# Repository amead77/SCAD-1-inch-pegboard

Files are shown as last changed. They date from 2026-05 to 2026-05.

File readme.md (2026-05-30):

# Pegboard tool holders in OpenSCAD

I designed this because I have 1" spaced pegboard, but wanted to be able to also do other peg spacing.

### It can be easily adapted to metric 25mm, or any other size, right within the customiser, so long as the holes are circular and in a square grid.

Everything about it is customisable. Maybe even for skadis, but I don't have any to test against. It would require offsetting each row of pegs though, because skadis offsets the rows from each other.

All the parts can be created from assembly.scad, by default it loads an overview.
By choosing which part to create, you can make any of the parts I've designed, in any size you want.

Before printing a bunch of stuff, I recommend doing a small print first to check the tolerances. My 0.4mm nozzle created nice 'n' tight fitting pegs, my 0.6mm created loose fitting pegs.

Print settings for supports I used were:

- Do not remove small overhangs.
- Tree supports

Very little special setup, just make sure the pegs are tree-supported. Normal supports not recommended.

Licence is CC-non commerical

AI used was co-pilot to refactor and help fix my mistakes. co-pilot is very good at that, but cannot (in my experience) create a openscad model from scratch.

Anyway, if you like the design, you're welcome to buy me a coffee:

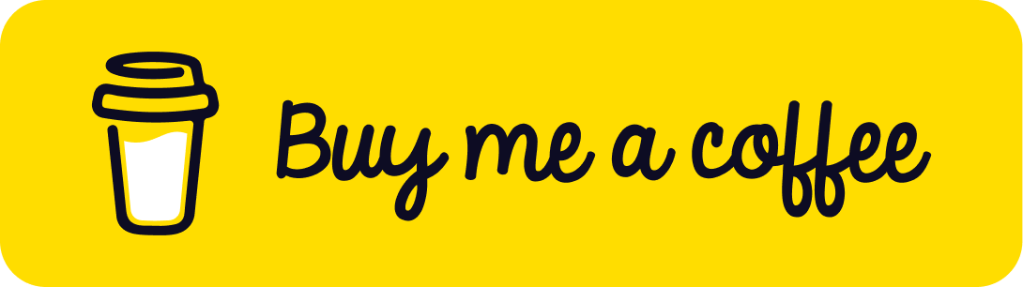
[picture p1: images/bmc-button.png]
Buy Me a Coffee


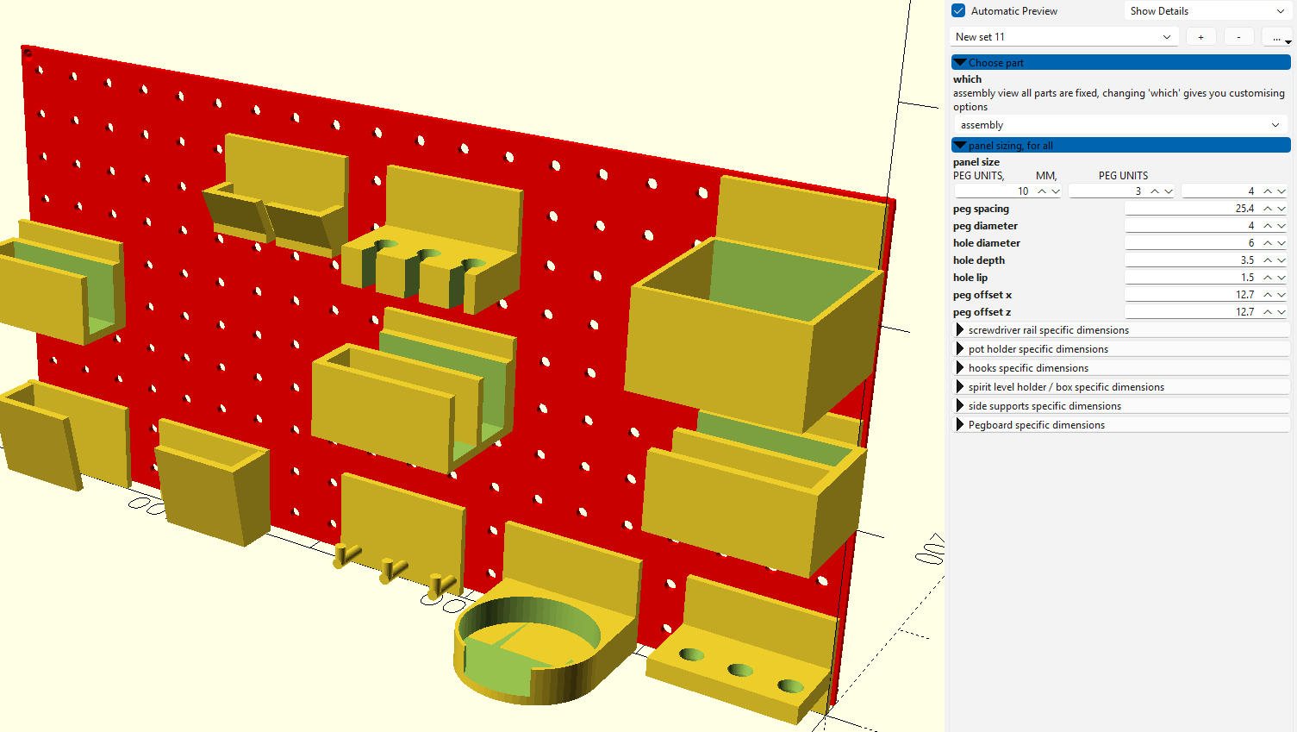
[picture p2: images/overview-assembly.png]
overview


Another view but with some basic models of stuff to show example usage

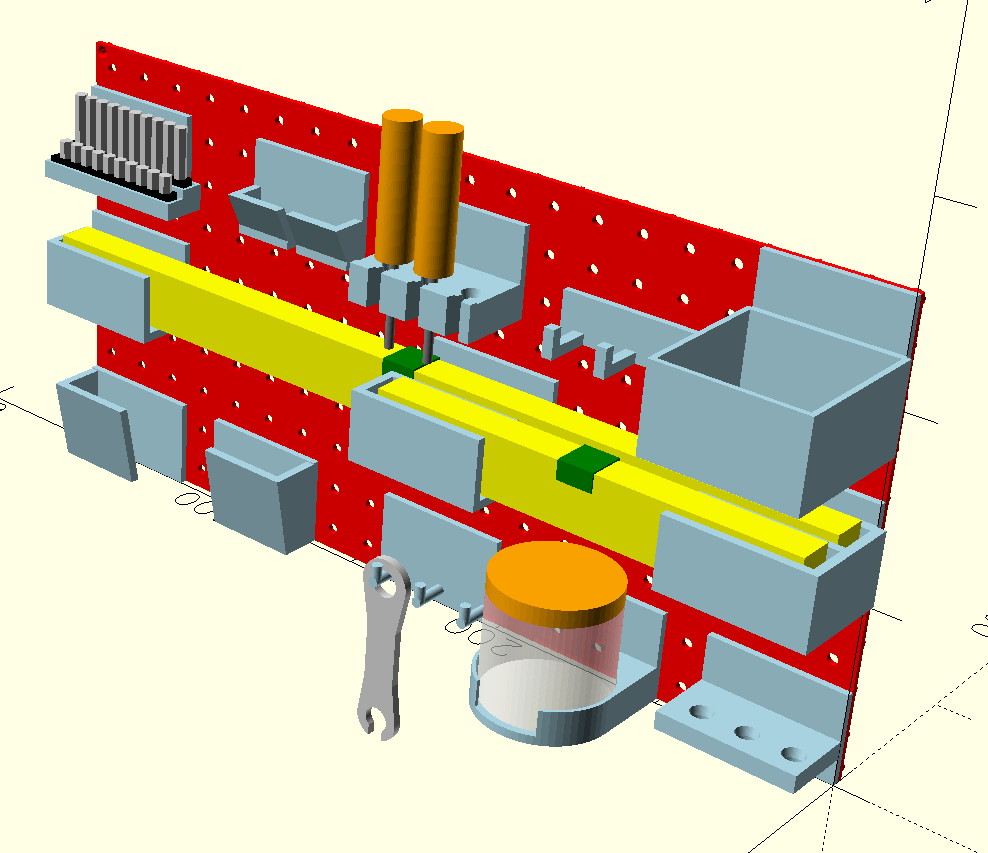
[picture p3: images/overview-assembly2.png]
overview2


A look at the back. The number of pegs is defined by the peg units.
The width and height of the back panel is defined by peg units and peg spacing. If you change to a 25mm peg spacing, it'll be smaller than my 25.4mm spaced ones.
The thickness of the peg panel back is in MM.

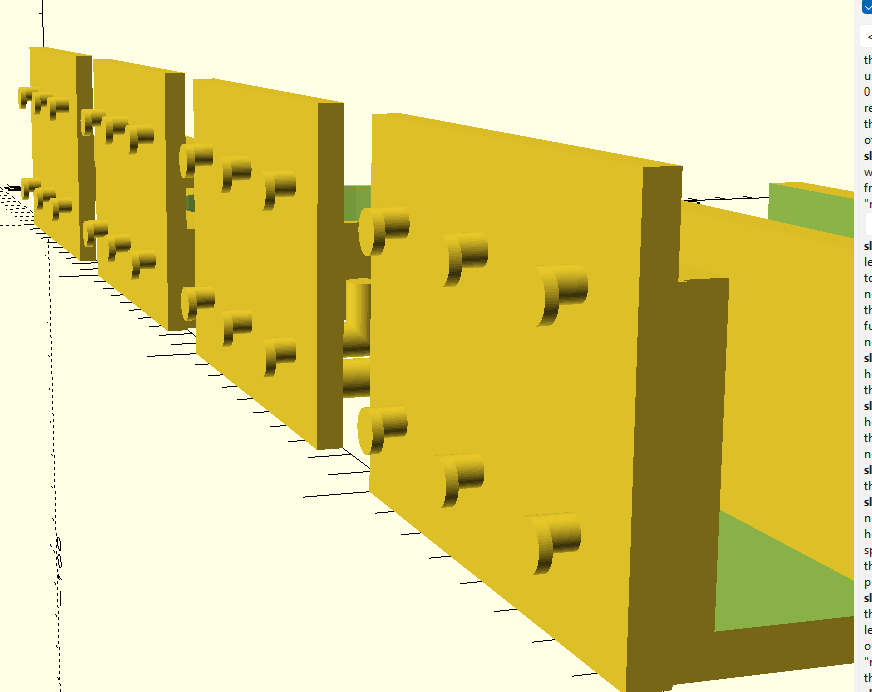
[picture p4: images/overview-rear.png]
overview-rear


You can use either my 'standard' pegs, or 'hooked' pegs (untested)

Hooked/Bent pegs (only the top one is curved)

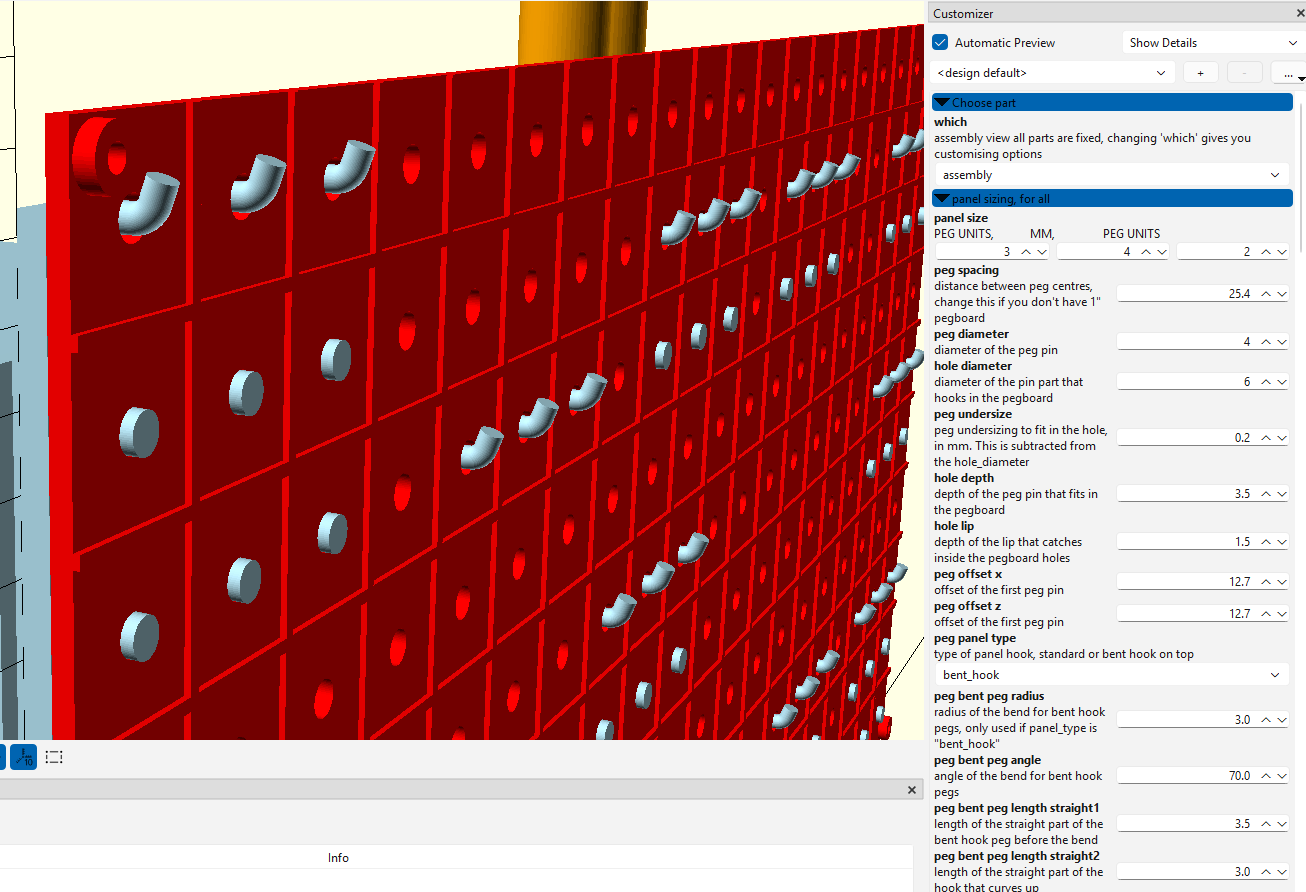
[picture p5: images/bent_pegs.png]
peg1


Standard pegs

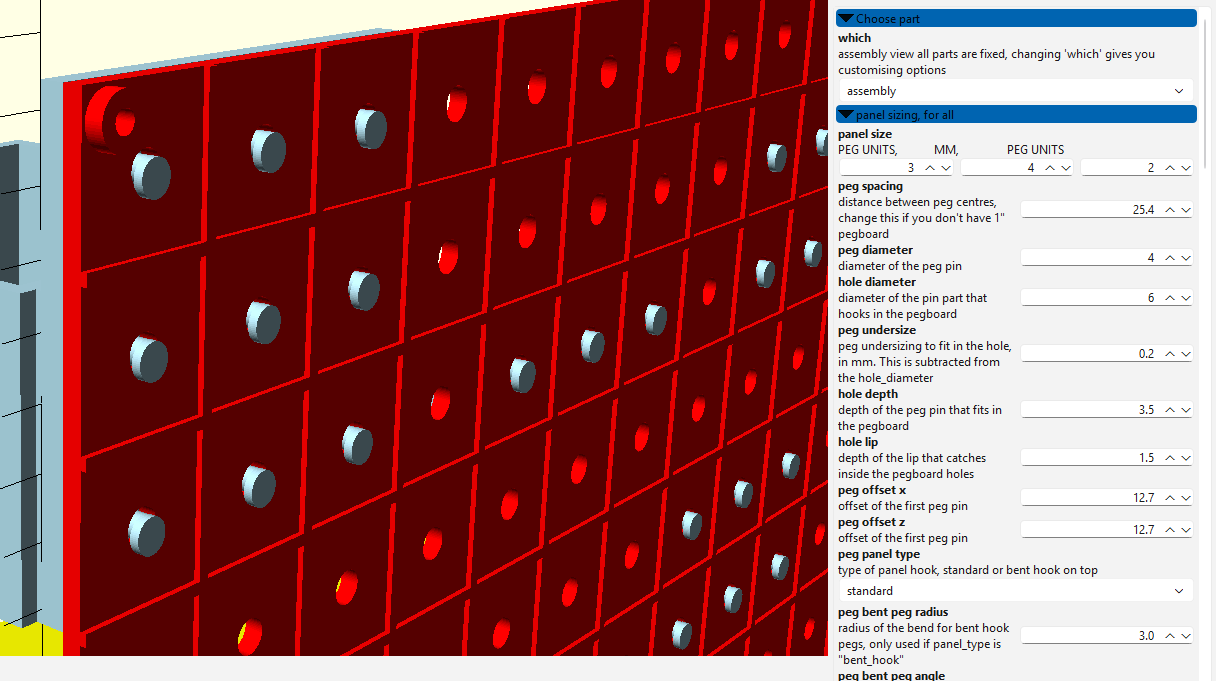
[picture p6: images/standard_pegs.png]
peg2


A small double box.

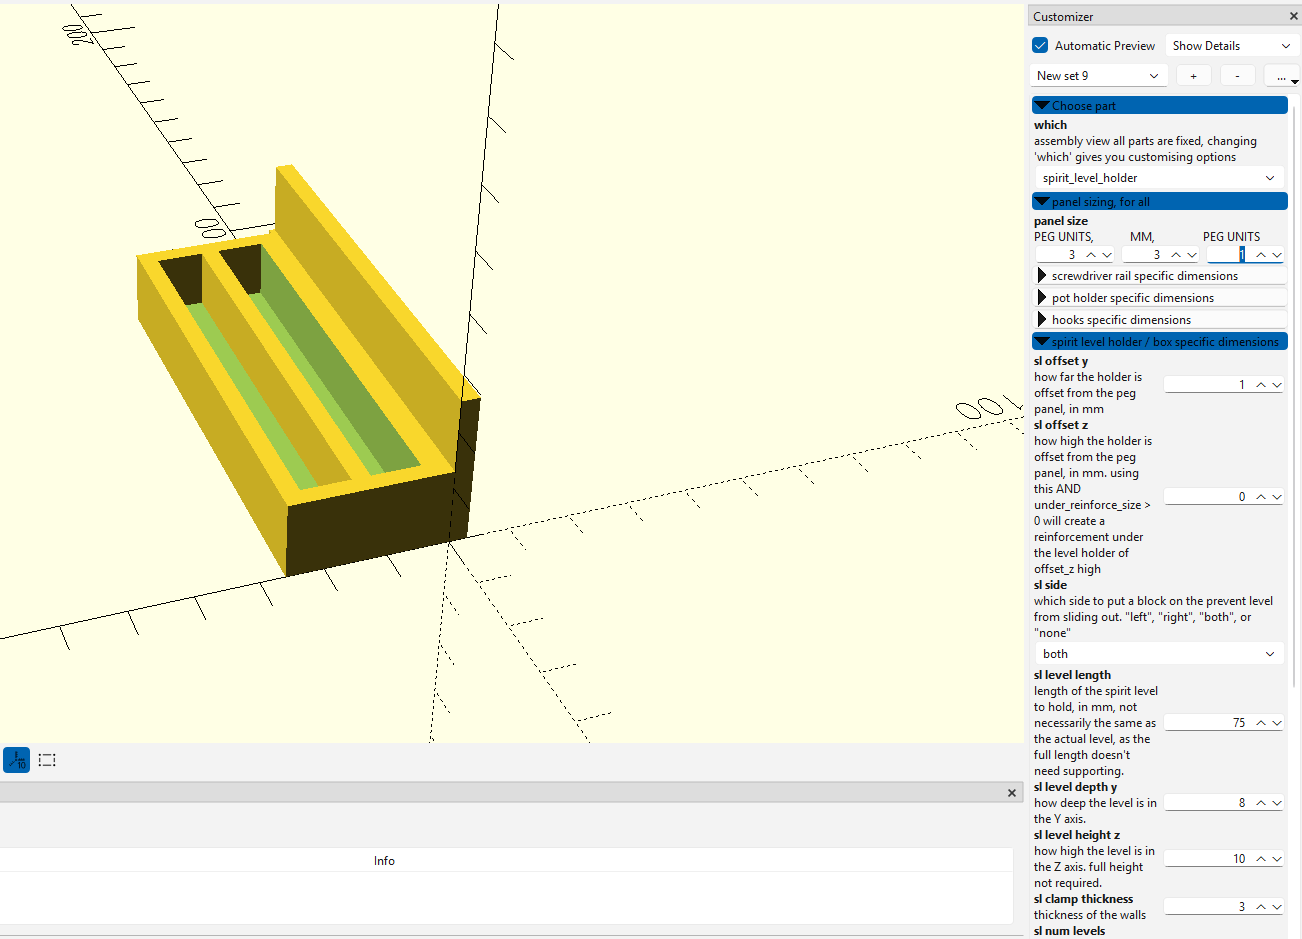
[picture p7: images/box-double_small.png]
doublebox


A pot holder with a front cutout

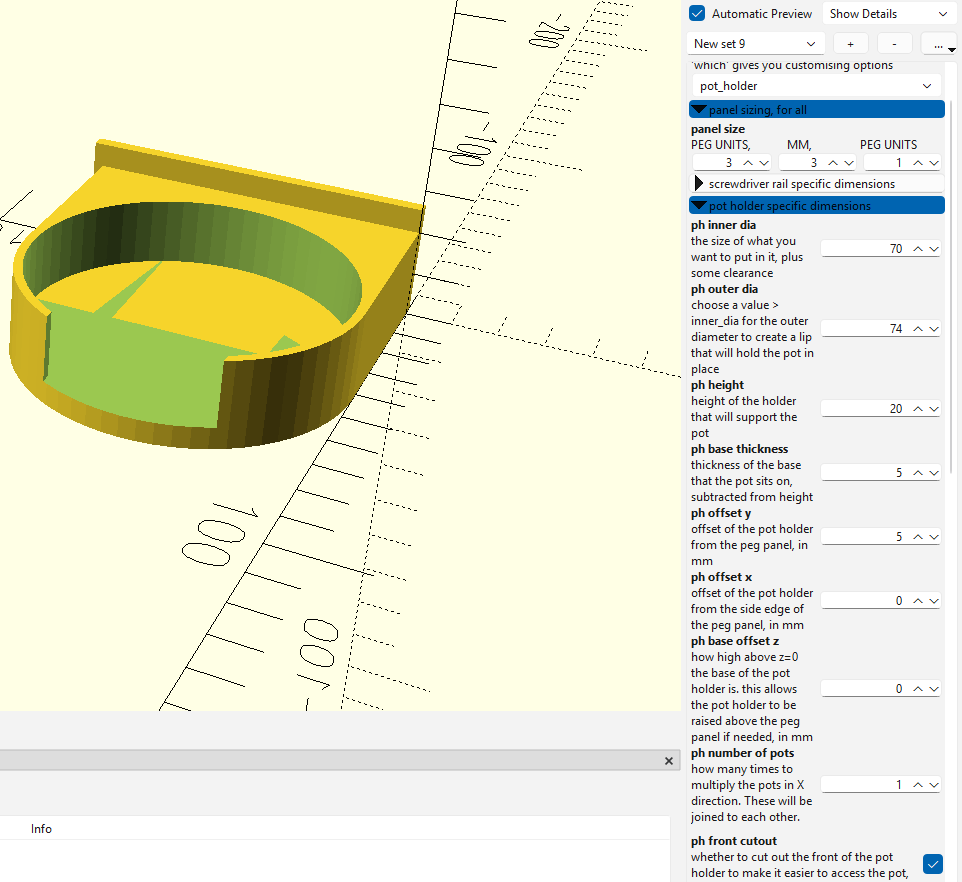
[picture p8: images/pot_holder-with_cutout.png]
pot


A small screwdriver rail

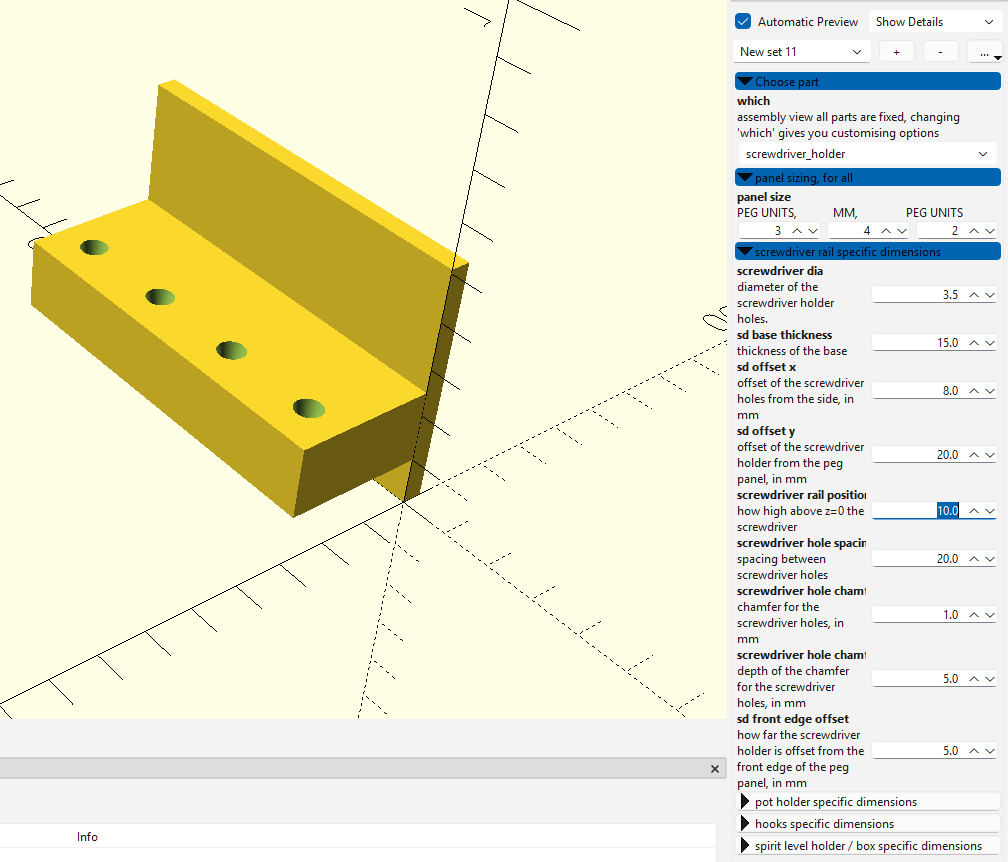
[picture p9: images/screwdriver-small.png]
screwd


The same rail, but with a cutout for inserting stuff from the front

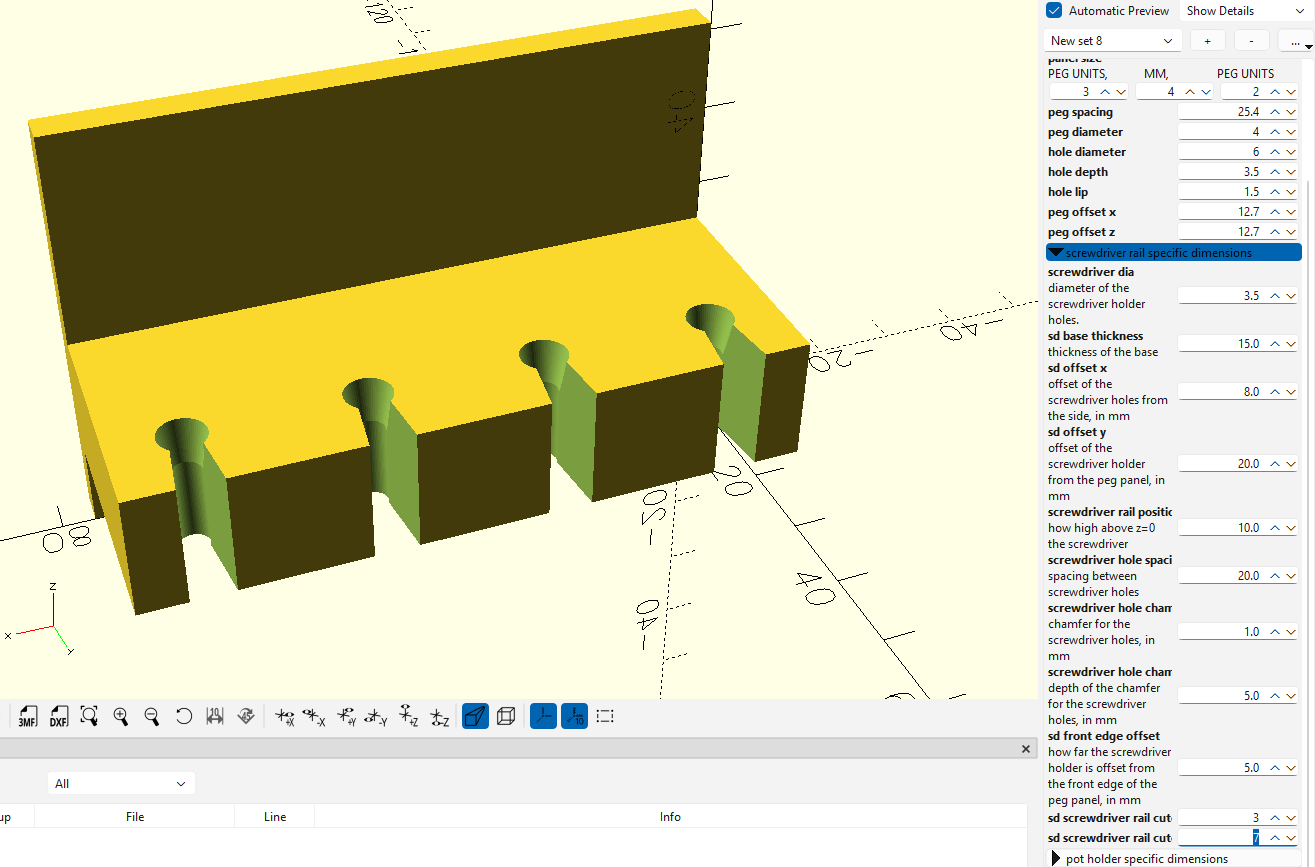
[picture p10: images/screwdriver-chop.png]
screwdc


How about some lips?

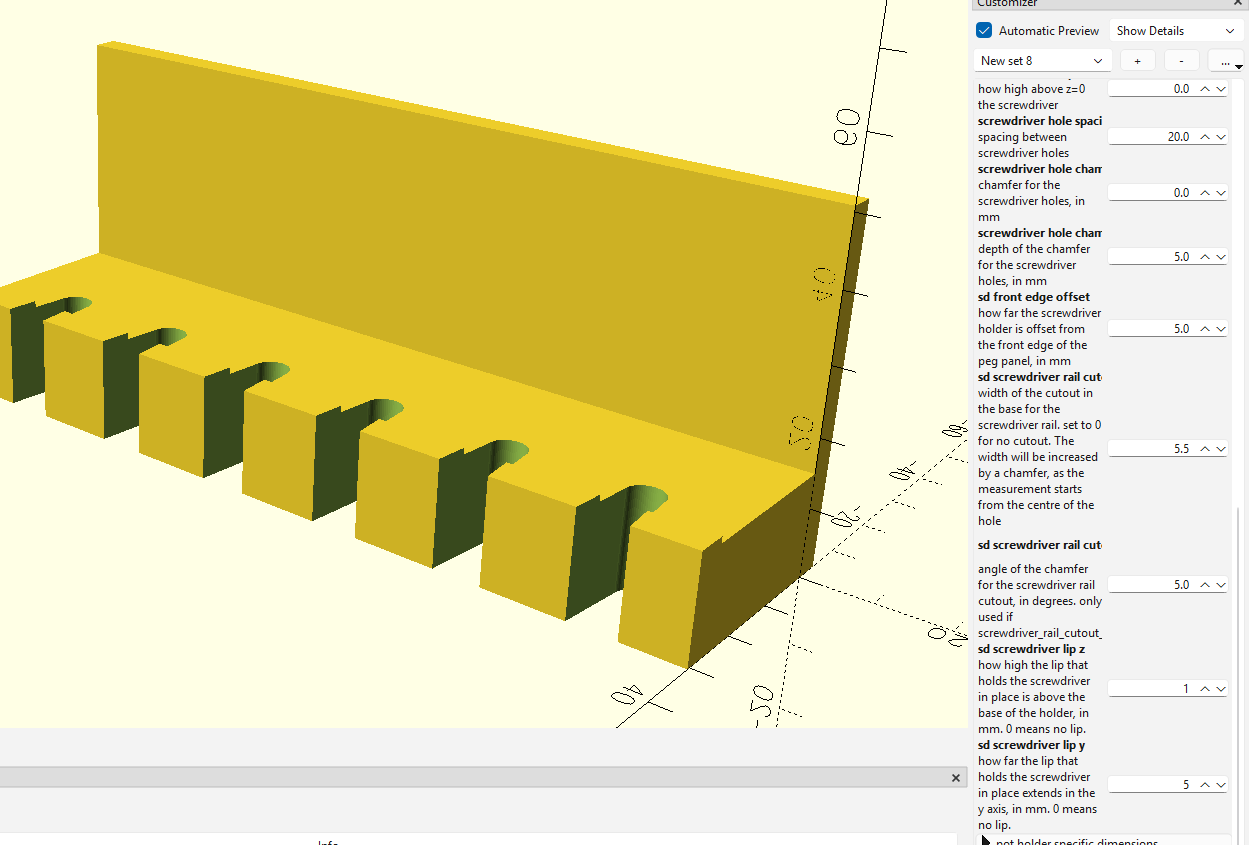
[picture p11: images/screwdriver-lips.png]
screwdd


You can also have Square Holes, for things like slotting in a vernier or something

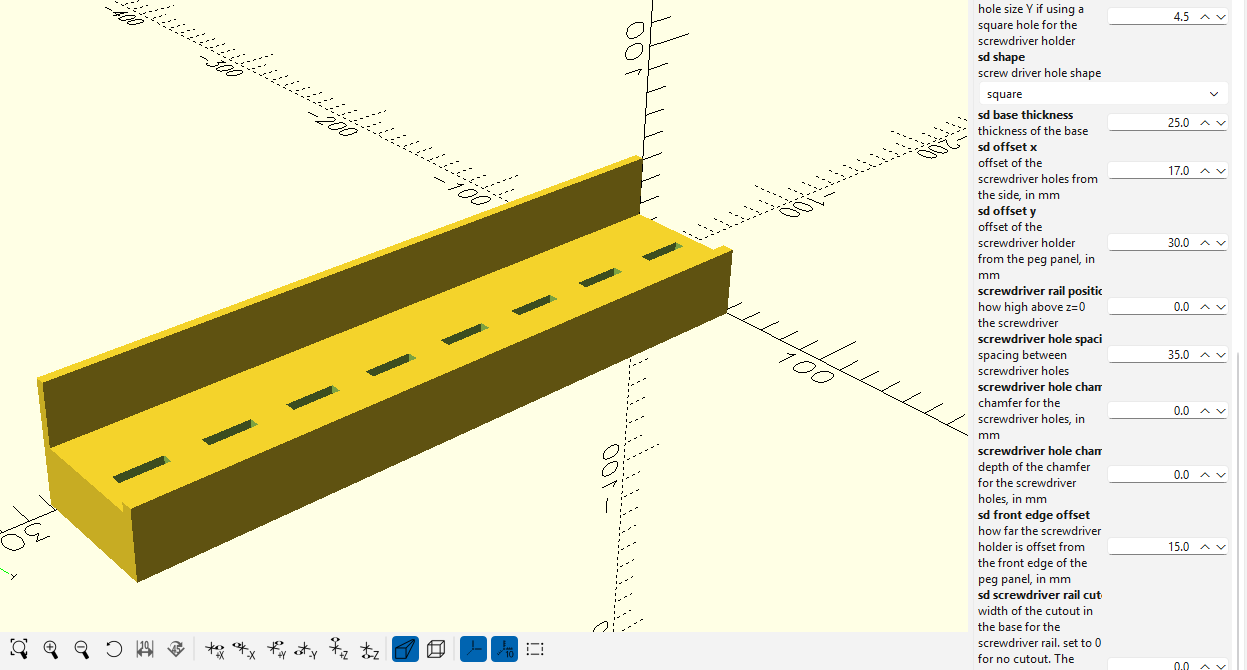
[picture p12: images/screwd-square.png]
screwde


Some hooks for hooky stuff, looks a bit jank because I didn't want to math out a curve, plus printing a upwards curve means supports for overhang.

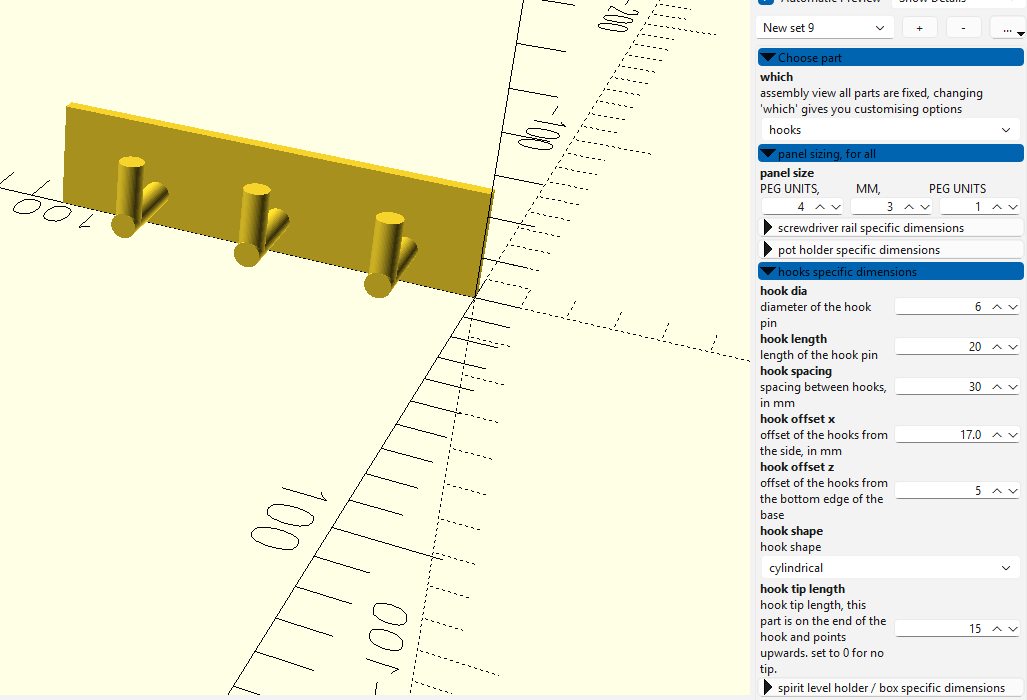
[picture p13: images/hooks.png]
hooks


Spirit level holder - this comes from the same model as the box, just by having the sides open.

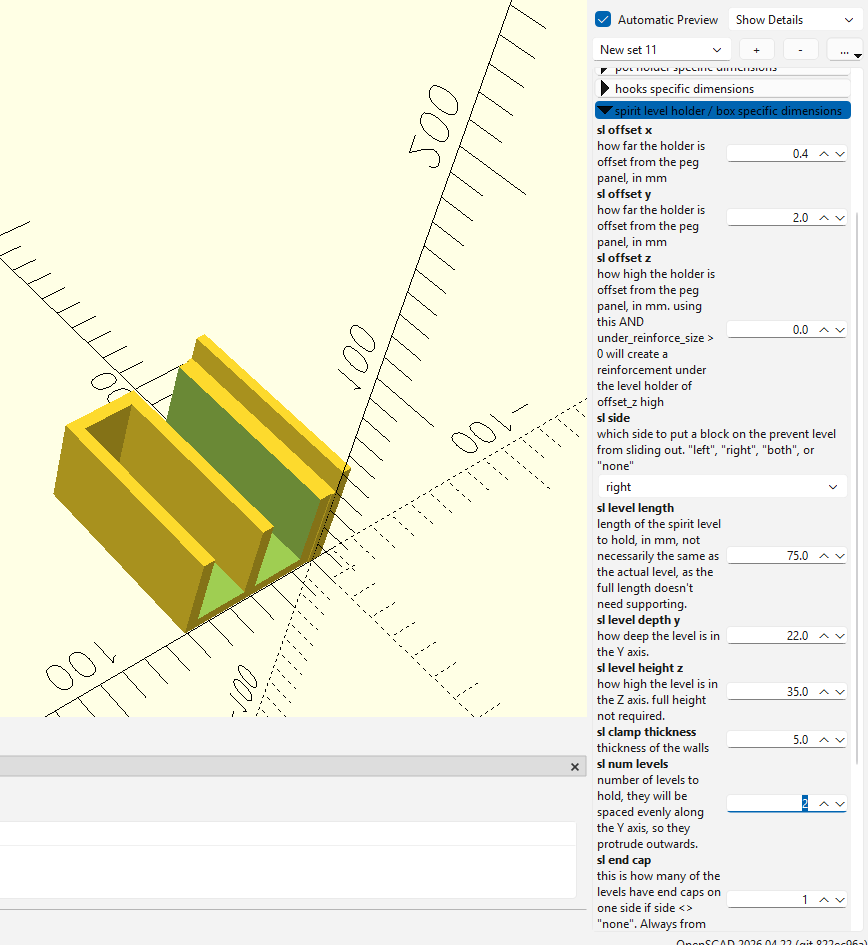
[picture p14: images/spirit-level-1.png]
level


By choosing a side, endcaps, and levels, you can create multi holders, some with openings, some without, at the same time if you want.

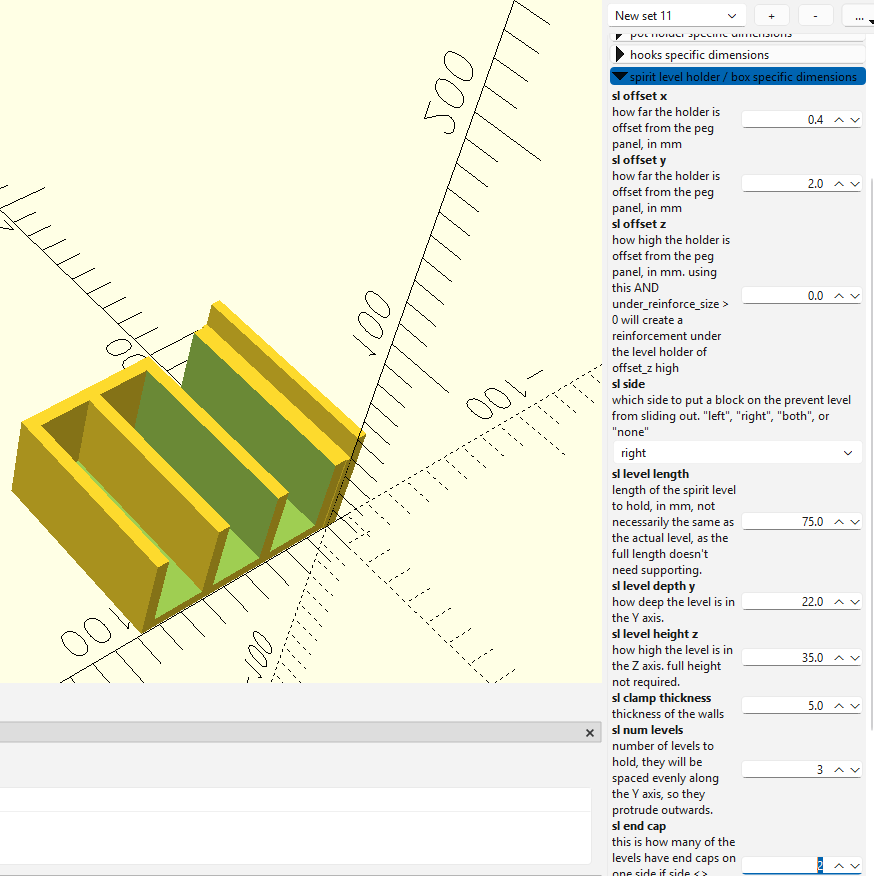
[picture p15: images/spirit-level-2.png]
level2


You can also set step_level in mm, to offset each part

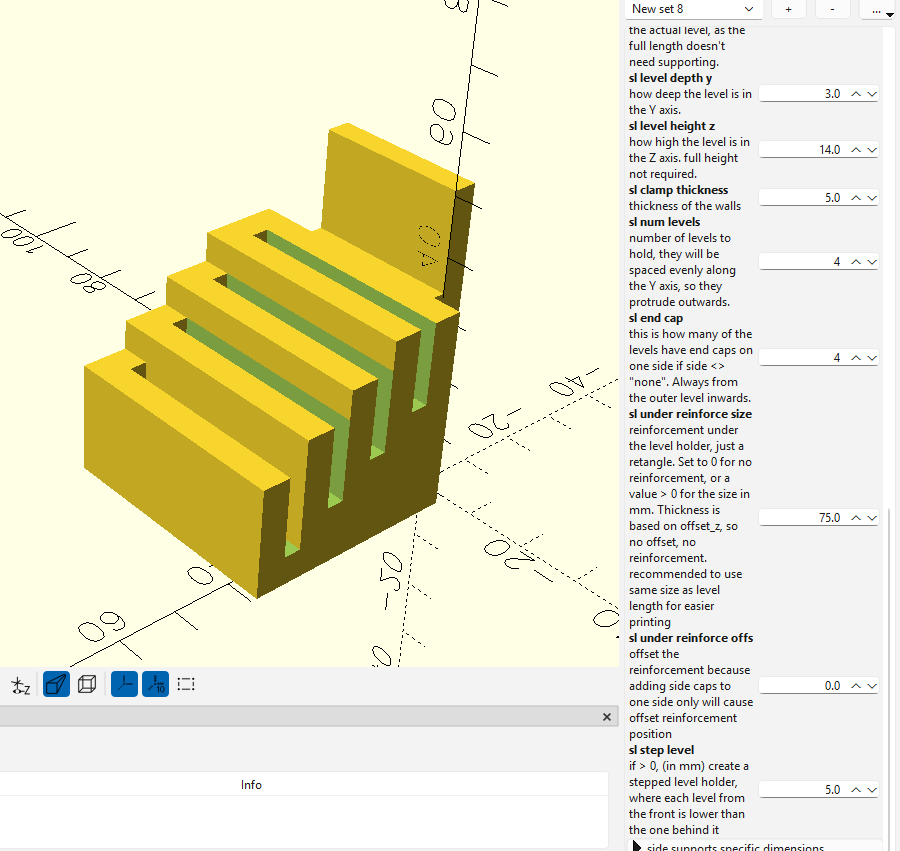
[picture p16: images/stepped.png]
level3


Side support, this is for supporting stuff from the side, can be angled. Stuff like laptops could be supported this way. Can be supported either or both sides, with or without the base.

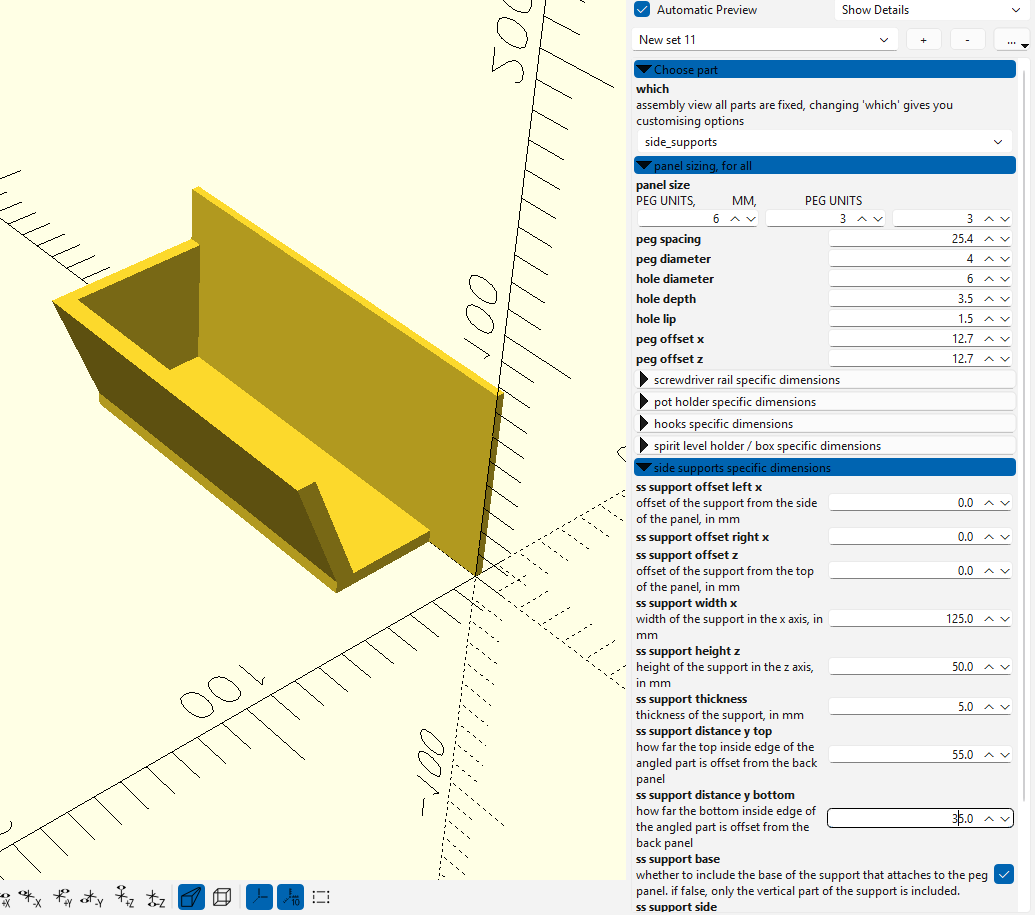
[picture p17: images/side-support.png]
sidesup


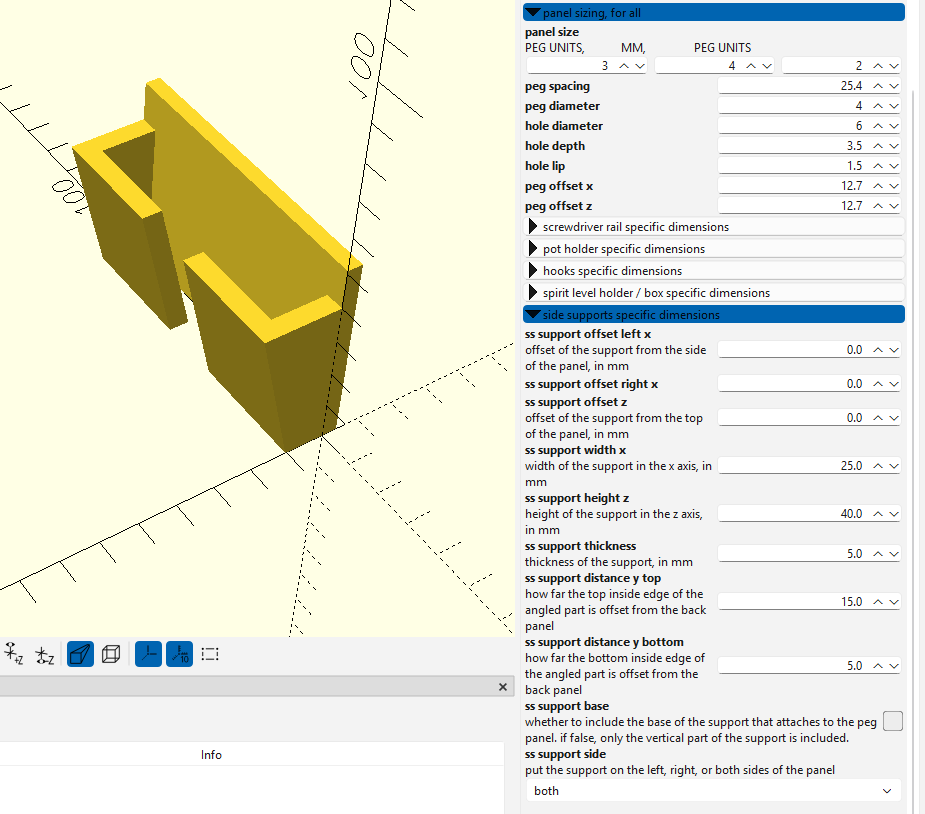
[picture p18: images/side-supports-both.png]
sidesip1


How about a custon pegboard? As many 'oles as you like.

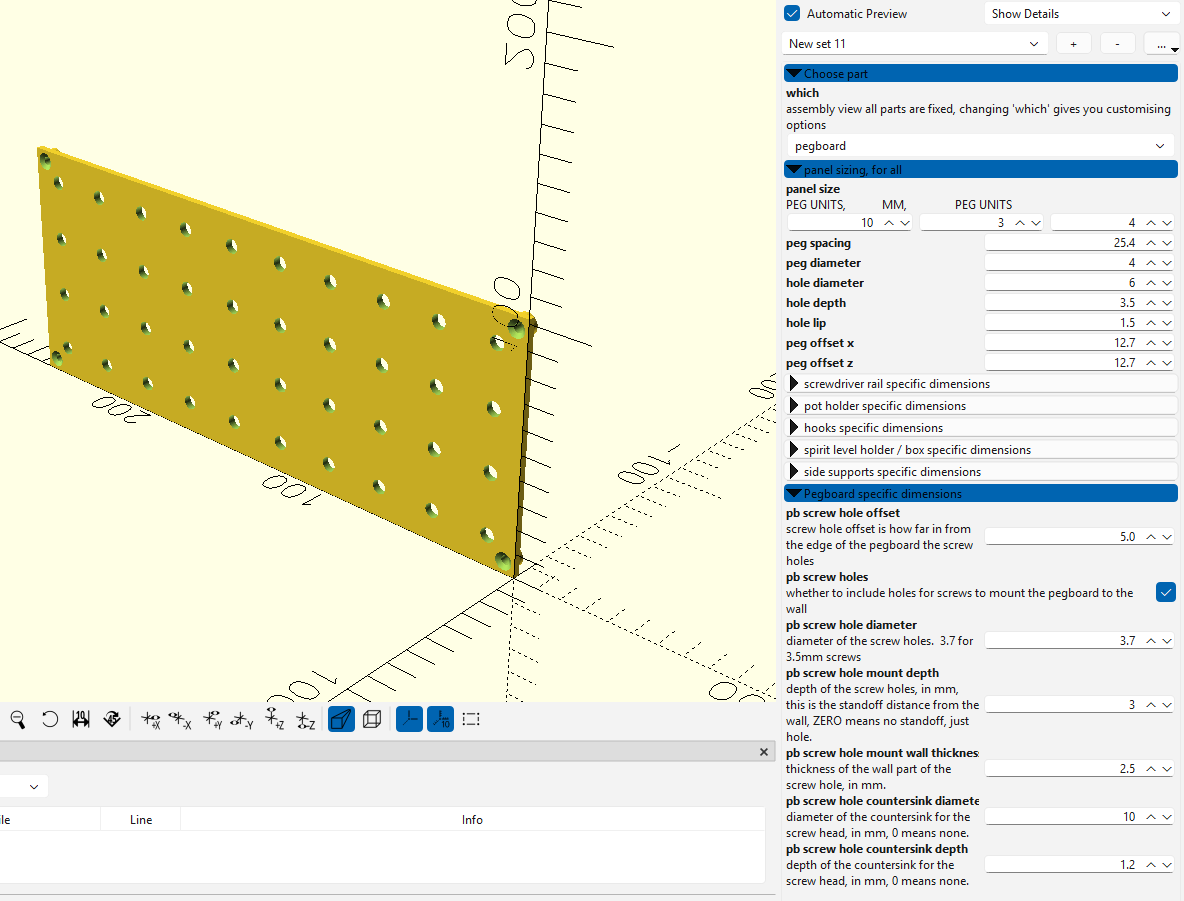
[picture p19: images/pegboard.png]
pegboard


Want a reinforced back to it? Sure!

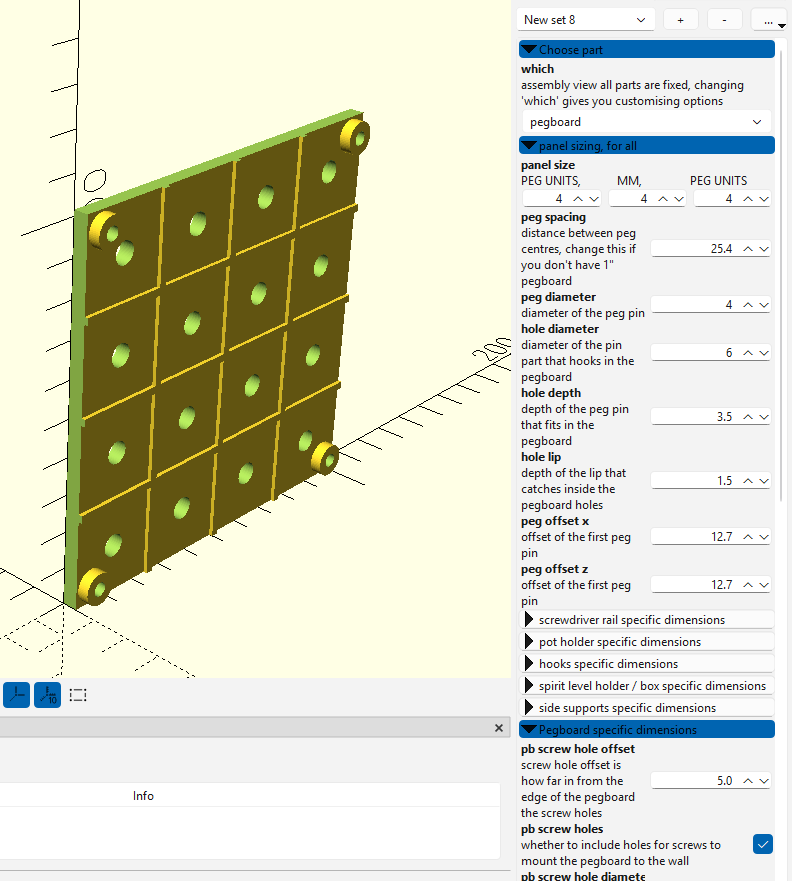
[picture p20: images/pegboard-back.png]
pegboard2


Some photos of what I've printed so far. Still printing more...

a

a

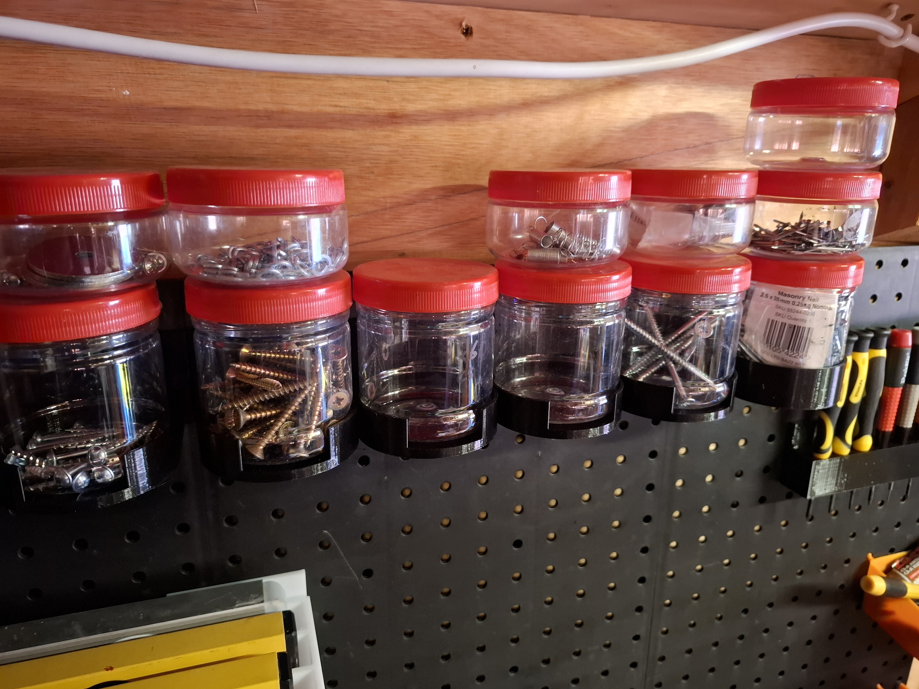
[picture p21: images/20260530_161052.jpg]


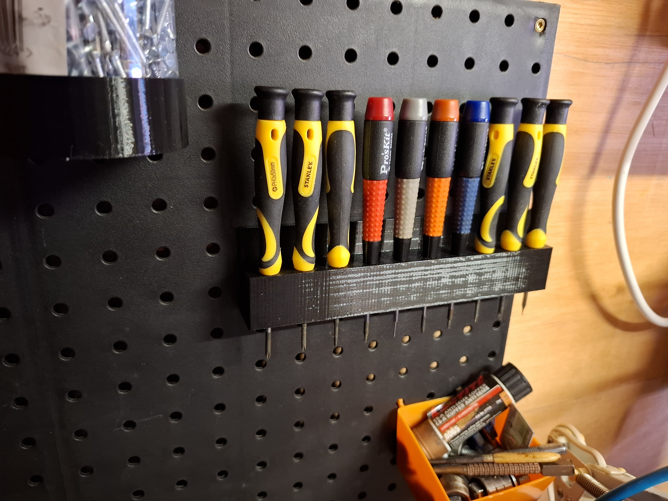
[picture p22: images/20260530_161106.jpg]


a

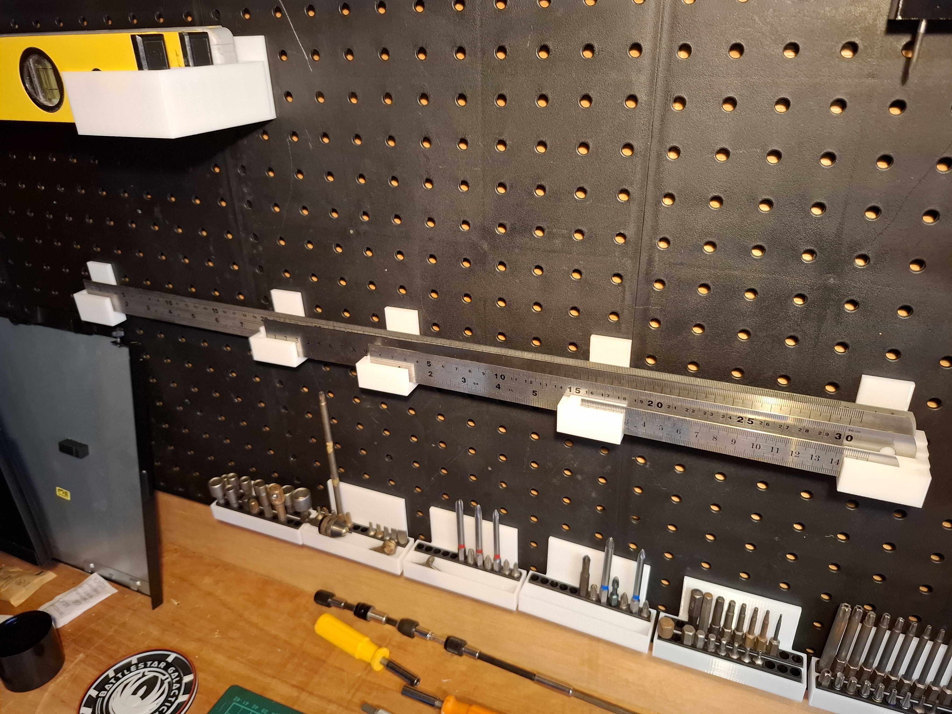
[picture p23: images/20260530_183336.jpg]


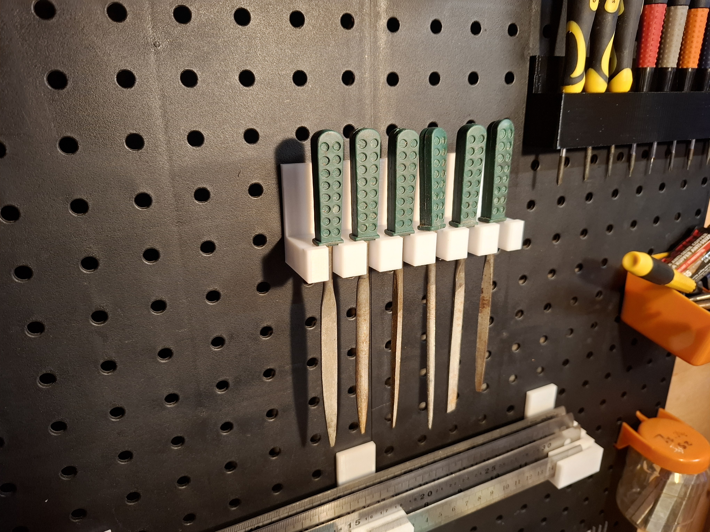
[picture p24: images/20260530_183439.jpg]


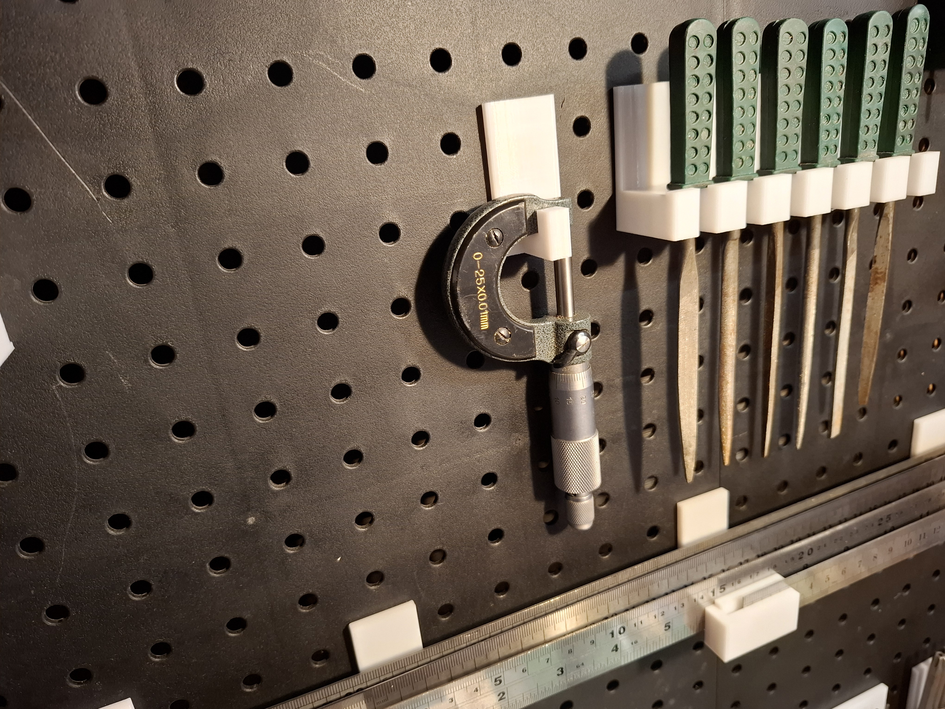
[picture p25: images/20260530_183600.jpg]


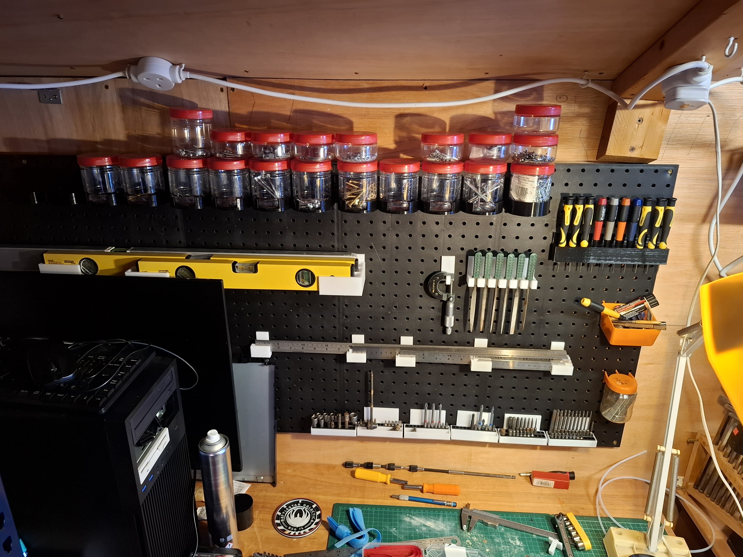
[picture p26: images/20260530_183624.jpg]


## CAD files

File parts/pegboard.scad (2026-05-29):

/*

a pegboard with holes for mounting stuff. based on peg panel sizing.

This was within AI's capabilities to generate, so i gave it all the parameters and 
initial code I'd written. After that I told it to modify the code to fix and add screw holes.

*/

module pegboard(
    //default is 1" spaced holes
    panel_size = [
        4, // in PEG SPACE UNITS, not mm
        3.2,  // thickness of the panel, in mm
        2 // in PEG SPACE UNITS, not mm
    ],     
    peg_spacing = 25.4, //distance between peg centres
    hole_diameter = 6.0, //diameter of hole for the peg pin, including the lip, so the peg can fit in.
    screw_holes = true, //whether to include holes for screws to mount the pegboard to the wall
    screw_hole_diameter = 3.7, //diameter of the screw holes. //3.7 for 3.5mm screws
    screw_hole_offset =  peg_spacing / 4, //distance of the screw holes from the edge of the pegboard, in mm
    screw_hole_mount_depth = 3, //depth of the screw holes, in mm, this is the standoff distance from the wall, ZERO means no standoff, just hole.
    screw_hole_mount_wall_thickness = 2.5, //thickness of the wall part of the screw hole, in mm.
    screw_hole_countersink_diameter = 10, //diameter of the countersink for the screw head, in mm, 0 means none.
    screw_hole_countersink_depth = 1.2, //depth of the countersink for the screw head, in mm, 0 means none.
    peg_offset_x = 12.7, //offset of the first peg pin
    peg_offset_z = 12.7, //offset of the first peg pin
    panel_reinforcement = true, //add a grid of lines on the back of the panel, half way between the peg holes
    panel_reinforcement_thickness = 2, //thickness (Z & X axis) of the reinforcement lines, in mm
    panel_reinforcement_depth = 1, //depth of the reinforcement lines, in mm (Y axis)
    panel_undersizing = 0.05 //how much to undersize the panel outer dimensions by, in mm. the same amount is applied to all 4 sides. this is for allowing 2 panels to be placed together without interference.
) {
    width_pegs = max(1, panel_size[0]);
    panel_y = panel_size[1];
    height_pegs = max(1, panel_size[2]);

    // Panel dimensions in mm, with offsets so pegs are not on edges.
    panel_x = (width_pegs - 1) * peg_spacing + 2 * peg_offset_x;
    panel_z = (height_pegs - 1) * peg_spacing + 2 * peg_offset_z;

    peg_count_x = width_pegs;
    peg_count_z = height_pegs;
    panel_undersize = max(0, panel_undersizing);
    rear_feature_depth = max(
        panel_reinforcement && panel_reinforcement_depth > 0 ? panel_reinforcement_depth : 0,
        screw_holes && screw_hole_mount_depth > 0 ? screw_hole_mount_depth : 0
    );
    screw_positions = [
        [screw_hole_offset, screw_hole_offset],
        [panel_x - screw_hole_offset, screw_hole_offset],
        [screw_hole_offset, panel_z - screw_hole_offset],
        [panel_x - screw_hole_offset, panel_z - screw_hole_offset]
    ];

    difference() {
        union() {
            // Front face is y=0. Panel depth extends toward -y.
            translate([0, -panel_y, 0])
                cube([panel_x, panel_y, panel_z], center = false);

            if (panel_reinforcement && panel_reinforcement_thickness > 0 && panel_reinforcement_depth > 0) {
                // Reinforcement ribs sit halfway between peg holes on the back face.
                for (ix = [0:peg_count_x - 2]) {
                    rib_x = peg_offset_x + (ix + 0.5) * peg_spacing - panel_reinforcement_thickness / 2;

                    translate([rib_x, -panel_y - panel_reinforcement_depth, 0])
                        cube([panel_reinforcement_thickness, panel_reinforcement_depth, panel_z], center = false);
                }

                for (iz = [0:peg_count_z - 2]) {
                    rib_z = peg_offset_z + (iz + 0.5) * peg_spacing - panel_reinforcement_thickness / 2;

                    translate([0, -panel_y - panel_reinforcement_depth, rib_z])
                        cube([panel_x, panel_reinforcement_depth, panel_reinforcement_thickness], center = false);
                }
            }

            if (screw_holes && screw_hole_mount_depth > 0) {
                for (position = screw_positions) {
                    translate([position[0], -panel_y, position[1]])
                        rotate([90, 0, 0])
                            cylinder(
                                d = screw_hole_diameter + 2 * screw_hole_mount_wall_thickness,
                                h = screw_hole_mount_depth
                            );
                }
            }
        }

        // Pegboard holes pass all the way through the panel.
        for (ix = [0:peg_count_x - 1]) {
            for (iz = [0:peg_count_z - 1]) {
                hole_x = peg_offset_x + ix * peg_spacing;
                hole_z = peg_offset_z + iz * peg_spacing;

                translate([hole_x, 1, hole_z])
                    rotate([90, 0, 0])
                        cylinder(d = hole_diameter, h = panel_y + 2);
            }
        }

        if (screw_holes) {
            for (position = screw_positions) {
                translate([position[0], 1, position[1]])
                    rotate([90, 0, 0])
                        cylinder(d = screw_hole_diameter, h = panel_y + screw_hole_mount_depth + 2);

                if (screw_hole_countersink_diameter > screw_hole_diameter && screw_hole_countersink_depth > 0) {
                    translate([position[0], 1, position[1]])
                        rotate([90, 0, 0])
                            cylinder(
                                d1 = screw_hole_countersink_diameter,
                                d2 = screw_hole_diameter,
                                h = screw_hole_countersink_depth + 1
                            );
                }
            }
        }

        if (panel_undersize > 0) {
            translate([-1, -panel_y - rear_feature_depth - 1, -1])
                cube([panel_undersize + 1, panel_y + rear_feature_depth + 2, panel_z + 2], center = false);

            translate([panel_x - panel_undersize, -panel_y - rear_feature_depth - 1, -1])
                cube([panel_undersize + 1, panel_y + rear_feature_depth + 2, panel_z + 2], center = false);

            translate([-1, -panel_y - rear_feature_depth - 1, -1])
                cube([panel_x + 2, panel_y + rear_feature_depth + 2, panel_undersize + 1], center = false);

            translate([-1, -panel_y - rear_feature_depth - 1, panel_z - panel_undersize])
                cube([panel_x + 2, panel_y + rear_feature_depth + 2, panel_undersize + 1], center = false);
        }
    }

}

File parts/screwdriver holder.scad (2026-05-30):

// small pot holder that attaches to a pegboard with 1" hole spacing.

/**
//next 2 lines used only by my 'on save' script. can be ignored otherwise.
//AUTO-V
version = "v0.1-2026/05/30r27";
**/

include <peg panel.scad>;
$fn = 64;

// dimensions of the pegboard holes
//hole_diameter = 6.5;
//hole_spacing = 25.4; // 1 inch
//hole_depth = 3.4;
//hole_lip = 1.0; // the lip that holds the peg in place

module makerail(rail_width, rail_front_y, base_thickness, screwdriver_lip_z = 3, screwdriver_lip_y = 5) {
    cube([
        rail_width, 
        rail_front_y, 
        base_thickness
    ], center = false);
    if (screwdriver_lip_z > 0 && screwdriver_lip_y > 0) {
        translate([0, rail_front_y - screwdriver_lip_y, base_thickness]) {
            cube([
                rail_width, 
                screwdriver_lip_y, 
                screwdriver_lip_z
            ], center = false);
        }
    }
}


module screwdriver_holder_assembly(
        panel_size = [
            3, // in PEG SPACE UNITS, not mm
            4, // thickness of the panel, in mm
            2 // in PEG SPACE UNITS, not mm
        ], 
        peg_spacing = 25.4, //distance between peg centres
        peg_diameter = 4.0, //diameter of the peg pin
        hole_diameter = 6.0, //diameter of the pin part that hooks in the pegboard
        peg_undersize = 0.2, //peg undersizing to fit in the hole, in mm. This is subtracted from the hole_diameter
        hole_depth = 3.5, //depth of the peg pin that fits in the pegboard
        hole_lip = 1.5, // depth of the lip that catches inside the pegboard holes
        peg_offset_x = 12.7, //offset of the first peg pin
        peg_offset_z = 12.7, //offset of the first peg pin          
        panel_type = "standard", // ["standard", "bent_hook"] type of panel hook, standard or bent hook on top
        bent_peg_radius = 3, // radius of the bend for bent hook pegs, only used if panel_type is "bent_hook"
        bent_peg_angle = 70, // angle of the bend for bent hook pegs
        bent_peg_length_straight1 = hole_depth, // length of the straight part of the bent hook peg before the bend
        bent_peg_length_straight2 = 4, // length of the straight part of the hook that curves up
        
        screwdriver_dia = 10, //diameter of the screwdriver holder holes.
        screwdriver_square_hole_size_x = 10, //hole size X if using a square hole for the screwdriver holder, ignored for round
        screwdriver_square_hole_size_y = 10, //hole size Y if using a square hole for the screwdriver holder
        screwdriver_shape = "round", // shape of the screwdriver holder holes. "round" or "square"
        screwdriver_hole_spacing = 25.4, //spacing between screwdriver holes
        screwdriver_hole_chamfer_width = 1, // chamfer for the screwdriver holes
        screwdriver_hole_chamfer_depth = 5, // depth of the chamfer for the screwdriver holes
        base_thickness = 8, //thickness of the base
        screwdriver_rail_cutout_width = 0, // width of the cutout in the base for the screwdriver rail. set to 0 for no cutout.
        screwdriver_rail_cutout_chamfer_angle = 20, // angle of the chamfer for the screwdriver rail cutout, in degrees. only used if screwdriver_rail_cutout_width > 0
        offset_x = 25, //offset of the screwdriver holes from the side, in mm
        offset_y = 25, //offset of the screwdriver holder from the peg panel, in mm
        front_edge_offset = 5, // how far the screwdriver holder is offset from the front edge of the peg panel, in mm
        screwdriver_rail_position = 20, //how high above z=0 the screwdriver rail and holes are. in mm
        screwdriver_lip_z = 0, // how high the lip that holds the screwdriver in place is above the base of the holder, in mm. 0 means no lip.
        screwdriver_lip_y = 0 // how far the lip that holds the screwdriver in place extends in the y axis, in mm. 0 means no lip.
        //hole_spacing = 25.4 // 1 inch - this is pegboard hole spacing, used to calculate the overall size of the panel and the number of holes.
    ) {
/*
This creates a pegboard screwdriver holder. it is offset away from the peg panel and joined to it.
the number of holes is determined by the panel size and the spacing between holes.
*/
    rail_width = panel_size[0] * peg_spacing;
    rail_front_y = offset_y + screwdriver_dia + front_edge_offset;
    cutout_run_y = max(0, rail_front_y - offset_y);
    cutout_front_width = screwdriver_rail_cutout_width + 2 * cutout_run_y * tan(screwdriver_rail_cutout_chamfer_angle);
    usable_width = max(0, rail_width - 2 * offset_x);
    hole_count = max(1, floor(usable_width / screwdriver_hole_spacing) + 1);
    base_top_z = screwdriver_rail_position + base_thickness;

        union() {
            // base of the screwdriver holder
            difference() {
                translate([0, 0, screwdriver_rail_position]) {
                    makerail(rail_width, rail_front_y, base_thickness, screwdriver_lip_z, screwdriver_lip_y);
                }
                // screwdriver holes
                for (i = [0:hole_count - 1]) {
                    if (screwdriver_shape == "round") {
                        translate([offset_x + i * screwdriver_hole_spacing, offset_y, screwdriver_rail_position - 5]) {
                            cylinder(d = screwdriver_dia, h = base_thickness+screwdriver_lip_z + 10); // extra height to ensure it cuts through the base
                        }
                    } else if (screwdriver_shape == "square") {
                        translate([offset_x + i * screwdriver_hole_spacing, offset_y, screwdriver_rail_position+((base_thickness+screwdriver_lip_z + 10)/2) - 5]) {
                            cube([screwdriver_square_hole_size_x, screwdriver_square_hole_size_y, base_thickness+screwdriver_lip_z + 10], center = true); // extra height to ensure it cuts through the base
                        }
                    }
                    translate([
                        offset_x + i * screwdriver_hole_spacing,
                        offset_y,
                        base_top_z - screwdriver_hole_chamfer_depth
                    ]) {
                            cylinder(
                                d1 = screwdriver_dia, 
                                d2 = screwdriver_dia + 2 * screwdriver_hole_chamfer_width, 
                                h = screwdriver_hole_chamfer_depth, center = false);
                    }
                    // cutout for the screwdriver rail, if specified
                    if (screwdriver_rail_cutout_width > 0) {
                        translate([
                            offset_x + i * screwdriver_hole_spacing,
                            0,
                            screwdriver_rail_position-5
                        ]) {
                            linear_extrude(height = base_thickness + screwdriver_lip_z + 10, center = false)
                                polygon([
                                    [-(screwdriver_rail_cutout_width / 2), offset_y],
                                    [ (screwdriver_rail_cutout_width / 2), offset_y],
                                    [ (cutout_front_width / 2), rail_front_y],
                                    [-(cutout_front_width / 2), rail_front_y]
                                ]);
                        }
                    }
                }
            }
            peg_panel(
                panel_size = panel_size,
                peg_spacing = peg_spacing,
                peg_diameter = peg_diameter,
                hole_diameter = hole_diameter,
                peg_undersize = peg_undersize,
                hole_depth = hole_depth,
                hole_lip = hole_lip,
                peg_offset_x = peg_offset_x,
                peg_offset_z = peg_offset_z,
                panel_type = panel_type,
                bent_peg_radius = bent_peg_radius,
                bent_peg_angle = bent_peg_angle,
                bent_peg_length_straight1 = bent_peg_length_straight1,
                bent_peg_length_straight2 = bent_peg_length_straight2
            );
        }

}

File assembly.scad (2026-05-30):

/*
this is the assembly view AND the main file that includes all the parts.
Use the customiser in openscad to choose which part, then adjust to suit.
If you don't want 1" spacing you can modify the "peg panel.scad". Or override
the defaults in peg panel.

when designing your own parts, in the assembly view note that the axis x,y is reversed
for the part you are making, because the wall pegs are on the 'front', so 
you're making on the back.
*/


/**
//next 2 lines used only by my 'on save' script. can be ignored otherwise.
//AUTO-V
version = "v0.1-2026/05/30r171";
**/



include <parts/screwdriver holder.scad>;
include <parts/pot holder.scad>;
include <parts/hooks.scad>;
include <parts/spirit level.scad>;
include <parts/side supports.scad>;
include <parts/pegboard.scad>;
include <parts-viewonly/basic-models.scad>;


/* [Choose part] */
// assembly view all parts are fixed, changing 'which' gives you customising options
which = "assembly"; // ["assembly", "screwdriver_holder", "pot_holder", "hooks", "BOX_and_spirit_level_holder", "side_supports", "pegboard"]

/* [panel sizing, for all] */
//PEG UNITS,            MM,                PEG UNITS
panel_size = [
    3, // in PEG SPACE UNITS, not mm
    4, // thickness of the panel, in mm
    2 // in PEG SPACE UNITS, not mm
];
//distance between peg centres, change this if you don't have 1" pegboard
peg_spacing = 25.4; 
//diameter of the peg pin
peg_diameter = 4.0; 
//diameter of the pin part that hooks in the pegboard
hole_diameter = 6.0; 
//peg undersizing to fit in the hole, in mm. This is subtracted from the hole_diameter
peg_undersize = 0.2;
//depth of the peg pin that fits in the pegboard
hole_depth = 3.5; 
// depth of the lip that catches inside the pegboard holes
hole_lip = 1.5; 
//offset of the first peg pin
peg_offset_x = 12.7; 
//offset of the first peg pin
peg_offset_z = 12.7; 
// type of panel hook, standard or bent hook on top
peg_panel_type = "standard"; // ["standard", "bent_hook"]
// radius of the bend for bent hook pegs, only used if panel_type is "bent_hook"
peg_bent_peg_radius = 3; //0.1
// angle of the bend for bent hook pegs
peg_bent_peg_angle = 70; //0.1
// length of the straight part of the bent hook peg before the bend
peg_bent_peg_length_straight1 = 3.5; //0.1
// length of the straight part of the hook that curves up
peg_bent_peg_length_straight2 = 3; //0.1


/* [screwdriver rail specific dimensions] */
//diameter of the screwdriver holder holes. Ignored for square holes
screwdriver_dia = 3.5;  // 0.1
//hole size X if using a square hole for the screwdriver holder, ignored for round
sd_square_hole_size_x = 5; // 0.1
//hole size Y if using a square hole for the screwdriver holder
sd_square_hole_size_y = 5; // 0.1
//screw driver hole shape
sd_shape = "round"; //["round", "square"]
//thickness of the base
sd_base_thickness = 15;  // 0.1
//offset of the screwdriver holes from the side, in mm
sd_offset_x = 8;  // 0.1
//offset of the screwdriver holder from the peg panel, in mm
sd_offset_y = 20;  // 0.1
//how high above z=0 the screwdriver
screwdriver_rail_position = 10;  // 0.1
//spacing between screwdriver holes
screwdriver_hole_spacing = 20.0;  // 0.1
// chamfer for the screwdriver holes, in mm
screwdriver_hole_chamfer_width = 1;  // 0.1
// depth of the chamfer for the screwdriver holes, in mm
screwdriver_hole_chamfer_depth = 5;  // 0.1
// how far the screwdriver holder is offset from the front edge of the peg panel, in mm
sd_front_edge_offset = 5;  // 0.1
// width of the cutout in the base for the screwdriver rail. set to 0 for no cutout. The width will be increased by a chamfer, as the measurement starts from the centre of the hole
sd_screwdriver_rail_cutout_width = 0;  // 0.1 
// angle of the chamfer for the screwdriver rail cutout, in degrees. only used if screwdriver_rail_cutout_width > 0
sd_screwdriver_rail_cutout_chamfer_angle = 20;  // 0.1 
// how high the lip that holds the screwdriver in place is above the base of the holder, in mm. 0 means no lip.
sd_screwdriver_lip_z = 1; 
// how far the lip that holds the screwdriver in place extends in the y axis, in mm. 0 means no lip.
sd_screwdriver_lip_y = 5; 

/* [pot holder specific dimensions] */
// the size of what you want to put in it, plus some clearance
ph_inner_dia = 70;  // 0.1
// choose a value > inner_dia for the outer diameter to create a lip that will hold the pot in place
ph_outer_dia = 74;  // 0.1
// height of the holder that will support the pot
ph_height = 20;  // 0.1
// thickness of the base that the pot sits on, subtracted from height
ph_base_thickness = 5;  // 0.1
// offset of the pot holder from the peg panel, in mm
ph_offset_y = 5;  // 0.1
// offset of the pot holder from the side edge of the peg panel, in mm
ph_offset_x = 0;  // 0.1
// how high above z=0 the base of the pot holder is. this allows the pot holder to be raised above the peg panel if needed, in mm
ph_base_offset_z = 0;  // 0.1
//how many times to multiply the pots in X direction. These will be joined to each other.
ph_number_of_pots = 1; 
// whether to cut out the front of the pot holder to make it easier to access the pot, default is 0.25% the diameter of the outer diameter
ph_front_cutout = true; 

/* [hooks specific dimensions] */
// diameter of the hook pin
hook_dia = 6.0; // 0.1
// length of the hook pin
hook_length = 20; // 0.1
// spacing between hooks, in mm
hook_spacing = 30.0; // 0.1
// offset of the hooks from the side, in mm
hook_offset_x = 12.7; // 0.1
// offset of the hooks from the bottom edge of the base
hook_offset_z = 5.0; // 0.1
// hook shape
hook_shape = "cylindrical"; // ["cylindrical", "square"]
//hook tip length, this part is on the end of the hook and points upwards. set to 0 for no tip.
hook_tip_length = 15;

/* [spirit level holder / box specific dimensions] */
// how far the holder is offset from the peg panel, in mm
sl_offset_x = 0.0; // 0.1
// how far the holder is offset from the peg panel, in mm
sl_offset_y = 2;  // 0.1
// how high the holder is offset from the peg panel, in mm. using this AND under_reinforce_size > 0 will create a reinforcement under the level holder of offset_z high
sl_offset_z = 0;  // 0.1
// which side to put a block on the prevent level from sliding out. "left", "right", "both", or "none"
sl_side = "right"; //["left", "right", "both", "none"]
// length of the spirit level to hold, in mm, not necessarily the same as the actual level, as the full length doesn't need supporting.
sl_level_length = 75;  // 0.1
//how deep the level is in the Y axis.
sl_level_depth_y = 22;  // 0.1
//how high the level is in the Z axis. full height not required.
sl_level_height_z = 35;  // 0.1
//thickness of the walls
sl_clamp_thickness = 5;  // 0.1
//number of levels to hold, they will be spaced evenly along the Y axis, so they protrude outwards.
sl_num_levels = 2;
//this is how many of the levels have end caps on one side if side <> "none". Always from the outer level inwards.
sl_end_cap = 2;
//reinforcement under the level holder, just a retangle. Set to 0 for no reinforcement, or a value > 0 for the size in mm. Thickness is based on offset_z, so no offset, no reinforcement. recommended to use same size as level length for easier printing
sl_under_reinforce_size = 75;  // 0.1
// offset the reinforcement because adding side caps to one side only will cause offset reinforcement position
sl_under_reinforce_offset_x = 0; // 0.1
// if > 0, (in mm) create a stepped level holder, where each level from the front is lower than the one behind it
sl_step_level = 0; // 0.01

/* [side supports specific dimensions] */
//offset of the support from the side of the panel, in mm
ss_support_offset_left_x = 0; //0.1
ss_support_offset_right_x = 0; //0.1
//offset of the support from the bottom of the panel, in mm
ss_support_offset_z = 0; //0.1
//width of the support in the x axis, in mm
ss_support_width_x = 25; //0.1
//height of the support in the z axis, in mm
ss_support_height_z = 50; //0.1
//thickness of the support, in mm
ss_support_thickness = 5; //0.1
//how far the top inside edge of the angled part is offset from the back panel
ss_support_distance_y_top = 15; //0.1
//how far the bottom inside edge of the angled part is offset from the back panel
ss_support_distance_y_bottom = 5; //0.1
//whether to include the base of the support that attaches to the peg panel. if false, only the vertical part of the support is included.
ss_support_base = true; //[true, false]
//put the support on the left, right, or both sides of the panel
ss_support_side = "both"; //["left", "right", "both"]
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

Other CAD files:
parts-viewonly/basic-models.scad
parts/hooks.scad
parts/peg panel.scad
parts/pot holder.scad
parts/side supports.scad
parts/spirit level.scad

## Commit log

2026-05-16 1 inch pegboard parts, initial commit
    [pot holder.scad]
2026-05-16 screwdriver rail, assembly
    [assembly.scad, peg panel.scad, screwdriver holder.scad]
2026-05-16 fixes and customisation
    [assembly.scad, peg panel.scad, pot holder.scad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]
2026-05-16 allow multi-pots
    [assembly.scad, pot holder.scad]
2026-05-16 variable name changes
    [assembly.scad, screwdriver holder.scad]
2026-05-16 pot front cutout
    [assembly.scad, pot holder.scad]
2026-05-16 start on hooks
    [assembly.scad, hooks.scad]
2026-05-17 add actual hooks to the hooks
    [assembly.scad, hooks.scad]
2026-05-25 spirit level initial
    [assembly.scad, spirit level.scad]
2026-05-25 allow full modification, images
    [assembly.scad, hooks.scad, pot holder.scad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]
2026-05-25 allow front slots in screwdriver rail
    [assembly.scad, screwdriver holder.scad]
2026-05-25 fix int to float
    [assembly.scad]
2026-05-25 fix box undersizing on x axis when adding sides
    [spirit level.scad]
2026-05-25 adding side support model
    [assembly.scad, side supports.scad, spirit level.scad]
2026-05-25 side support still not working, rethinking approach
    [side supports.scad]
2026-05-29 under reinforcement x pos
    [assembly.scad, spirit level.scad]
2026-05-29 getting there with the side supports
    [assembly.scad, side supports.scad]
2026-05-29 side supports working
    [assembly.scad, side supports.scad]
2026-05-29 update customiser
    [assembly.scad]
2026-05-29 side supports, comments
    [side supports.scad]
2026-05-29 correction to base support
    [assembly.scad, side supports.scad]
2026-05-29 fix base support
    [side supports.scad]
2026-05-29 fix z_offset in side support
    [assembly.scad, side supports.scad]
2026-05-29 add ribs to pegboard panel
    [pegboard.scad]
2026-05-29 pegboard reinforce
    [assembly.scad, pegboard.scad]
2026-05-30 added a stepping to the box/spirit level holder
    [assembly.scad, spirit level.scad]
2026-05-30 add lips to screwdriver rail
    [assembly.scad, screwdriver holder.scad]
2026-05-30 fix to allow undersizing pegs
    [assembly.scad, hooks.scad, peg panel.scad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]
2026-05-30 more assembly view. prep move parts
    [assembly.scad]
2026-05-30 moved files to ./parts
    [hooks.scad, peg panel.scad, pegboard.scad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]
2026-05-30 add basic models to assembly view
    [assembly.scad, spiritlevel.scad]
2026-05-30 add models, readme, layout for ass. view
    [assembly.scad, basic-models.scad, spiritlevel.scad]
2026-05-30 allow square 'oles in screwdriver rail
    [assembly.scad, peg panel.scad, screwdriver holder.scad]
2026-05-30 adding bent hooks to pegboard type
    [assembly.scad, hooks.scad, peg panel.scad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]
2026-05-30 bent peg working, need to update assembly still
    [peg panel.scad]
2026-05-30 hooked/bent pegs for the pegboard attachment
    [assembly.scad, hooks.scad, peg panel.scad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]
2026-05-30 switch default hook type
    [assembly.scad]
